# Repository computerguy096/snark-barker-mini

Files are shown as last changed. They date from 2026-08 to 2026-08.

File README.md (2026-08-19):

# The Snark Barker Mini - a miniaturized SB 1.0 Clone

The Snark Barker Mini is a function compatible clone of the original [Snark Barker](https://github.com/schlae/snark-barker), made by schlae. It implements all the features of the original Sound Blaster:

- OPL2 FM synth
- digital sound playback and recording
- gameport with MIDI IN/OUT
- SAA1099 (Creative Music System) synth 

The only major difference is the lack of a volume potentiometer. Due to the card's size and parts availability contraints, the volume is pre-set at max output, but this should not be a problem for speaker systems which have adjustable volume.

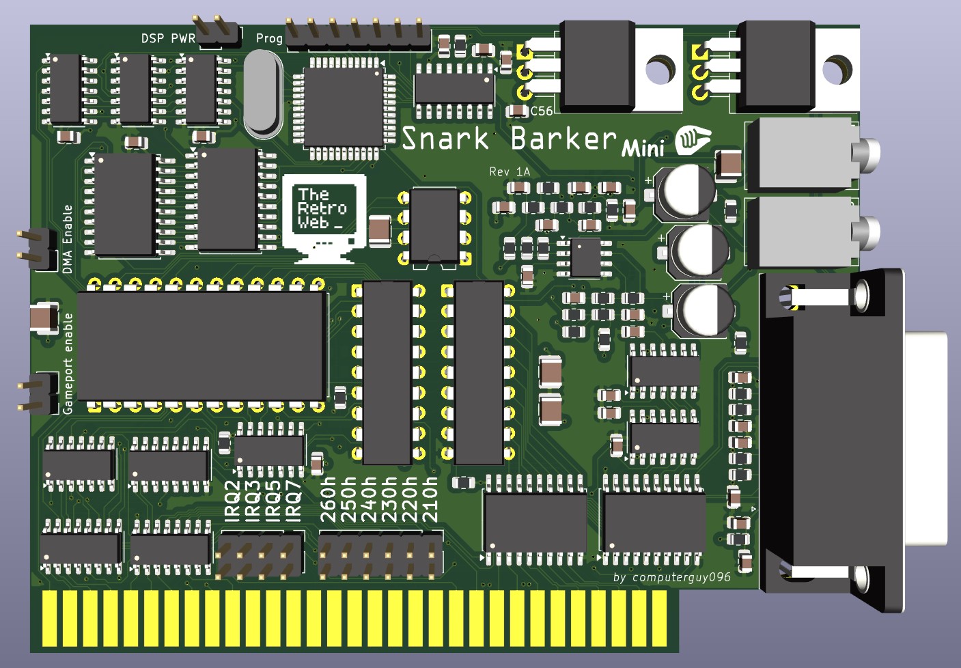
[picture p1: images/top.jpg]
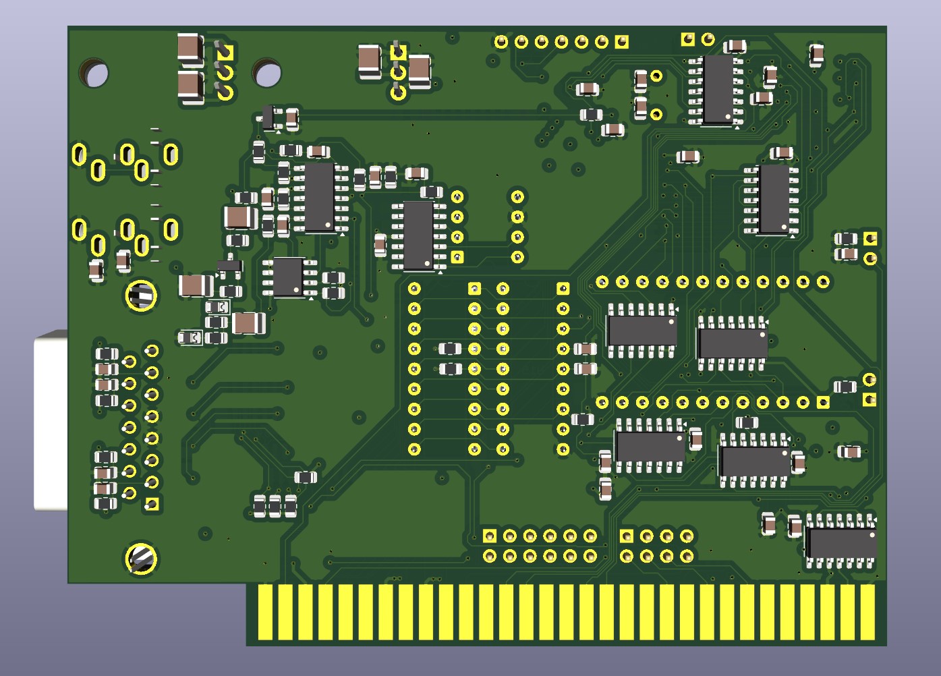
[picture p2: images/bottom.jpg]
 

## Bill Of Materials
An interactive HTML BOM is provided in `/kicad/bom` for easy parts installation. Most passives do not have silkscreen labels so this will be needed. Additionally, a CSV BOM is provided as well.

## The Firmware
This card uses an Atmel 89LP51 as a modern day replacement for the original 80C51 microcontroller Creative used to implement the DSP chip. There is a programming header provided for the DSP chip, which can be flashed with [this HEX file](firmware/sb.hex) using the tool of your choice. 

The DSP PWR jumper needs to be installed for normal operation, and removed when programming the DSP (it connects the DSP to VCC).

## Testing and Diagnostics
The card can be tested using schlae's [SBDIAG](utility/SBDIAG.EXE)

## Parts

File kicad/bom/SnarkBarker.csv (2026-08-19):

Reference | Qty | Value | DNP | Exclude from BOM | Exclude from Board | Footprint | Datasheet
C1,C2 | 2 | 30p |  |  |  | Capacitor_SMD:C_0805_2012Metric | ~
C3,C4,C37,C46,C48 | 5 | 330p |  |  |  | Capacitor_SMD:C_0805_2012Metric | ~
C5,C7 | 2 | 270p |  |  |  | Capacitor_SMD:C_0805_2012Metric | ~
C6 | 1 | 470p |  |  |  | Capacitor_SMD:C_0805_2012Metric | ~
C8 | 1 | 680p |  |  |  | Capacitor_SMD:C_0805_2012Metric | ~
C9,C10,C11,C12 | 4 | 10n |  |  |  | Capacitor_SMD:C_0805_2012Metric | ~
C13,C14,C15,C19,C20,C21,C22,C41,C45,C49,C50,C51,C52,C53,C56,C59,C60,C61,C62,C63,C64,C65,C66,C67,C68,C69,C70,C71,C72 | 29 | 100n |  |  |  | Capacitor_SMD:C_0805_2012Metric | ~
C16,C17,C18 | 3 | 22n |  |  |  | Capacitor_SMD:C_0805_2012Metric | ~
C23 | 1 | 4.7n |  |  |  | Capacitor_SMD:C_0805_2012Metric | ~
C24,C36,C39,C42,C54,C55,C57,C58,C73,C74,C75 | 11 | 10uF |  |  |  | Capacitor_SMD:C_1210_3225Metric | ~
C25,C26,C38 | 3 | 1n |  |  |  | Capacitor_SMD:C_0805_2012Metric | ~
C27,C28,C47 | 3 | 2.2n |  |  |  | Capacitor_SMD:C_0805_2012Metric | ~
C29,C30,C31 | 3 | 1uF |  |  |  | Capacitor_SMD:C_0805_2012Metric | ~
C32,C33,C43 | 3 | 100uF |  |  |  | Capacitor_SMD:CP_Elec_6.3x5.2 | ~
C34,C35 | 2 | 100p |  |  |  | Capacitor_SMD:C_0805_2012Metric | ~
C40,C44 | 2 | 47p |  |  |  | Capacitor_SMD:C_0805_2012Metric | ~
CN1 | 1 | GAME |  |  |  | Connector_Dsub:DSUB-15_Pins_Horizontal_P2.77x2.84mm_EdgePinOffset7.70mm_Housed_MountingHolesOffset9.12mm | ~
CN2 | 1 | SPKOUT |  |  |  | SB:TRS jack | ~
CN3 | 1 | MIC |  |  |  | SB:TRS jack | ~
D1,D2 | 2 | 1N4148 |  |  |  | Diode_SMD:D_0805_2012Metric | https://assets.nexperia.com/documents/data-sheet/1N4148_1N4448.pdf
J1 | 1 | Prog |  |  |  | Connector_PinHeader_2.54mm:PinHeader_1x07_P2.54mm_Vertical | ~
JP1 | 1 | I/O ADDX |  |  |  | Connector_PinHeader_2.54mm:PinHeader_2x06_P2.54mm_Vertical | ~
JP2 | 1 | IRQ |  |  |  | Connector_PinHeader_2.54mm:PinHeader_2x04_P2.54mm_Vertical | ~
JP3 | 1 | Gameport enable |  |  |  | Connector_PinHeader_2.54mm:PinHeader_1x02_P2.54mm_Vertical | ~
JP4 | 1 | DMA Enable |  |  |  | Connector_PinHeader_2.54mm:PinHeader_1x02_P2.54mm_Vertical | ~
JP5 | 1 | DSP PWR |  |  |  | Connector_PinHeader_2.54mm:PinHeader_1x02_P2.54mm_Vertical | ~
Q1,Q2 | 2 | 2N3904 |  |  |  | Package_TO_SOT_SMD:SOT-23 | https://www.onsemi.com/pub/Collateral/2N3903-D.PDF
R1,R2,R4,R20,R48,R55 | 6 | 4.7K |  |  |  | Resistor_SMD:R_0805_2012Metric | ~
R3,R5,R6,R7,R8,R9,R10,R11,R12,R36,R37 | 11 | 1K |  |  |  | Resistor_SMD:R_0805_2012Metric | ~
R13,R14,R15,R16 | 4 | 2k |  |  |  | Resistor_SMD:R_0805_2012Metric | ~
R17 | 1 | 47 |  |  |  | Resistor_SMD:R_0805_2012Metric | ~
R18,R19,R24,R25,R41 | 5 | 10K |  |  |  | Resistor_SMD:R_0805_2012Metric | ~
R21 | 1 | 2.2K |  |  |  | Resistor_SMD:R_0805_2012Metric | ~
R22,R23,R50 | 3 | 1.5K |  |  |  | Resistor_SMD:R_0805_2012Metric | ~
R26,R27 | 2 | 47K |  |  |  | Resistor_SMD:R_0805_2012Metric | ~
R28,R29,R54 | 3 | 27K |  |  |  | Resistor_SMD:R_0805_2012Metric | ~
R30,R31 | 2 | 15K |  |  |  | Resistor_SMD:R_0805_2012Metric | ~
R32,R33,R34,R35 | 4 | 20K |  |  |  | Resistor_SMD:R_0805_2012Metric | ~
R38,R39,R52 | 3 | 68K |  |  |  | Resistor_SMD:R_0805_2012Metric | ~
R40,R47,R53 | 3 | 470K |  |  |  | Resistor_SMD:R_0805_2012Metric | ~
R42,R44 | 2 | 470 |  |  |  | Resistor_SMD:R_0805_2012Metric | ~
R43 | 1 | 33K |  |  |  | Resistor_SMD:R_0805_2012Metric | ~
R45,R51 | 2 | 39K |  |  |  | Resistor_SMD:R_0805_2012Metric | ~
R46 | 1 | 100K |  |  |  | Resistor_SMD:R_0805_2012Metric | ~
R49 | 1 | 2.7K |  |  |  | Resistor_SMD:R_0805_2012Metric | ~
SL1 | 1 | 8-bit ISA slot |  |  |  | SB:ISA card edge | https://en.wikipedia.org/wiki/Industry_Standard_Architecture
U1 | 1 | L7805 |  |  |  | Package_TO_SOT_THT:TO-220-3_Horizontal_TabDown | http://www.st.com/content/ccc/resource/technical/document/datasheet/41/4f/b3/b0/12/d4/47/88/CD00000444.pdf/files/CD00000444.pdf/jcr:content/translations/en.CD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
U2 | 1 | L7905 |  |  |  | Package_TO_SOT_THT:TO-220-3_Horizontal_TabDown | http://www.st.com/content/ccc/resource/technical/document/datasheet/c9/16/86/41/c7/2b/45/f2/CD00000450.pdf/files/CD00000450.pdf/jcr:content/translations/en.CD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
U3 | 1 | DAC0808 |  |  |  | Package_SO:SOIC-16_3.9x9.9mm_P1.27mm | http://www.ti.com/lit/ds/symlink/dac0808.pdf
U4 | 1 | AT89LP51 |  |  |  | Package_QFP:TQFP-44_10x10mm_P0.8mm | https://ww1.microchip.com/downloads/en/DeviceDoc/doc2487.pdf
U5,U14,U25 | 3 | 74LS32 |  |  |  | Package_SO:SOIC-14_3.9x8.7mm_P1.27mm | http://www.ti.com/lit/gpn/sn74LS32
U6,U23,U27,U28 | 4 | 74LS74 |  |  |  | Package_SO:SOIC-14_3.9x8.7mm_P1.27mm | 74xx/74hc_hct74.pdf
U6,U28 | 2 | 74LS74 |  |  |  |  | 74xx/74hc_hct74.pdf
U7 | 1 | 74LS125 |  |  |  | Package_SO:SOIC-14_3.9x8.7mm_P1.27mm | http://www.ti.com/lit/gpn/sn74LS125
U8,U9 | 2 | 74LS374 |  |  |  | Package_SO:SOIC-20W_7.5x12.8mm_P1.27mm | http://www.ti.com/lit/gpn/sn74LS374
U10 | 1 | YM3014 |  |  |  | Package_DIP:DIP-8_W7.62mm
U11,U12 | 2 | SAA1099 |  |  |  | Package_DIP:DIP-18_W7.62mm
U13 | 1 | YM3812 |  |  |  | Package_DIP:DIP-24_W15.24mm
U15 | 1 | 74LS139 |  |  |  | Package_SO:SOIC-16_3.9x9.9mm_P1.27mm | http://www.ti.com/lit/ds/symlink/sn74ls139a.pdf
U16,U24,U26 | 3 | 74LS08 |  |  |  | Package_SO:SOIC-14_3.9x8.7mm_P1.27mm | http://www.ti.com/lit/gpn/sn74LS08
U17,U18 | 2 | 74LS138 |  |  |  | Package_SO:SOIC-16_3.9x9.9mm_P1.27mm | http://www.ti.com/lit/gpn/sn74LS138
U19,U20 | 2 | 74LS245 |  |  |  | Package_SO:SOIC-20W_7.5x12.8mm_P1.27mm | http://www.ti.com/lit/gpn/sn74LS245
U21,U22 | 2 | NE556 |  |  |  | Package_SO:SOIC-14_3.9x8.7mm_P1.27mm | http://www.ti.com/lit/ds/symlink/ne556.pdf
U29 | 1 | 74LS14 |  |  |  | Package_SO:SOIC-14_3.9x8.7mm_P1.27mm | http://www.ti.com/lit/gpn/sn74LS14
U30,U31 | 2 | LM324 |  |  |  | Package_SO:SOIC-14_3.9x8.7mm_P1.27mm | http://www.ti.com/lit/ds/symlink/lm2902-n.pdf
U32 | 1 | LM393 |  |  |  | Package_SO:SOIC-8_3.9x4.9mm_P1.27mm | http://www.ti.com/lit/ds/symlink/lm393.pdf
U33 | 1 | LM4880MX |  |  |  | Package_SO:SO-8_3.9x4.9mm_P1.27mm
Y1 | 1 | 12MHz |  |  |  | Crystal:Crystal_HC49-U_Vertical | ~

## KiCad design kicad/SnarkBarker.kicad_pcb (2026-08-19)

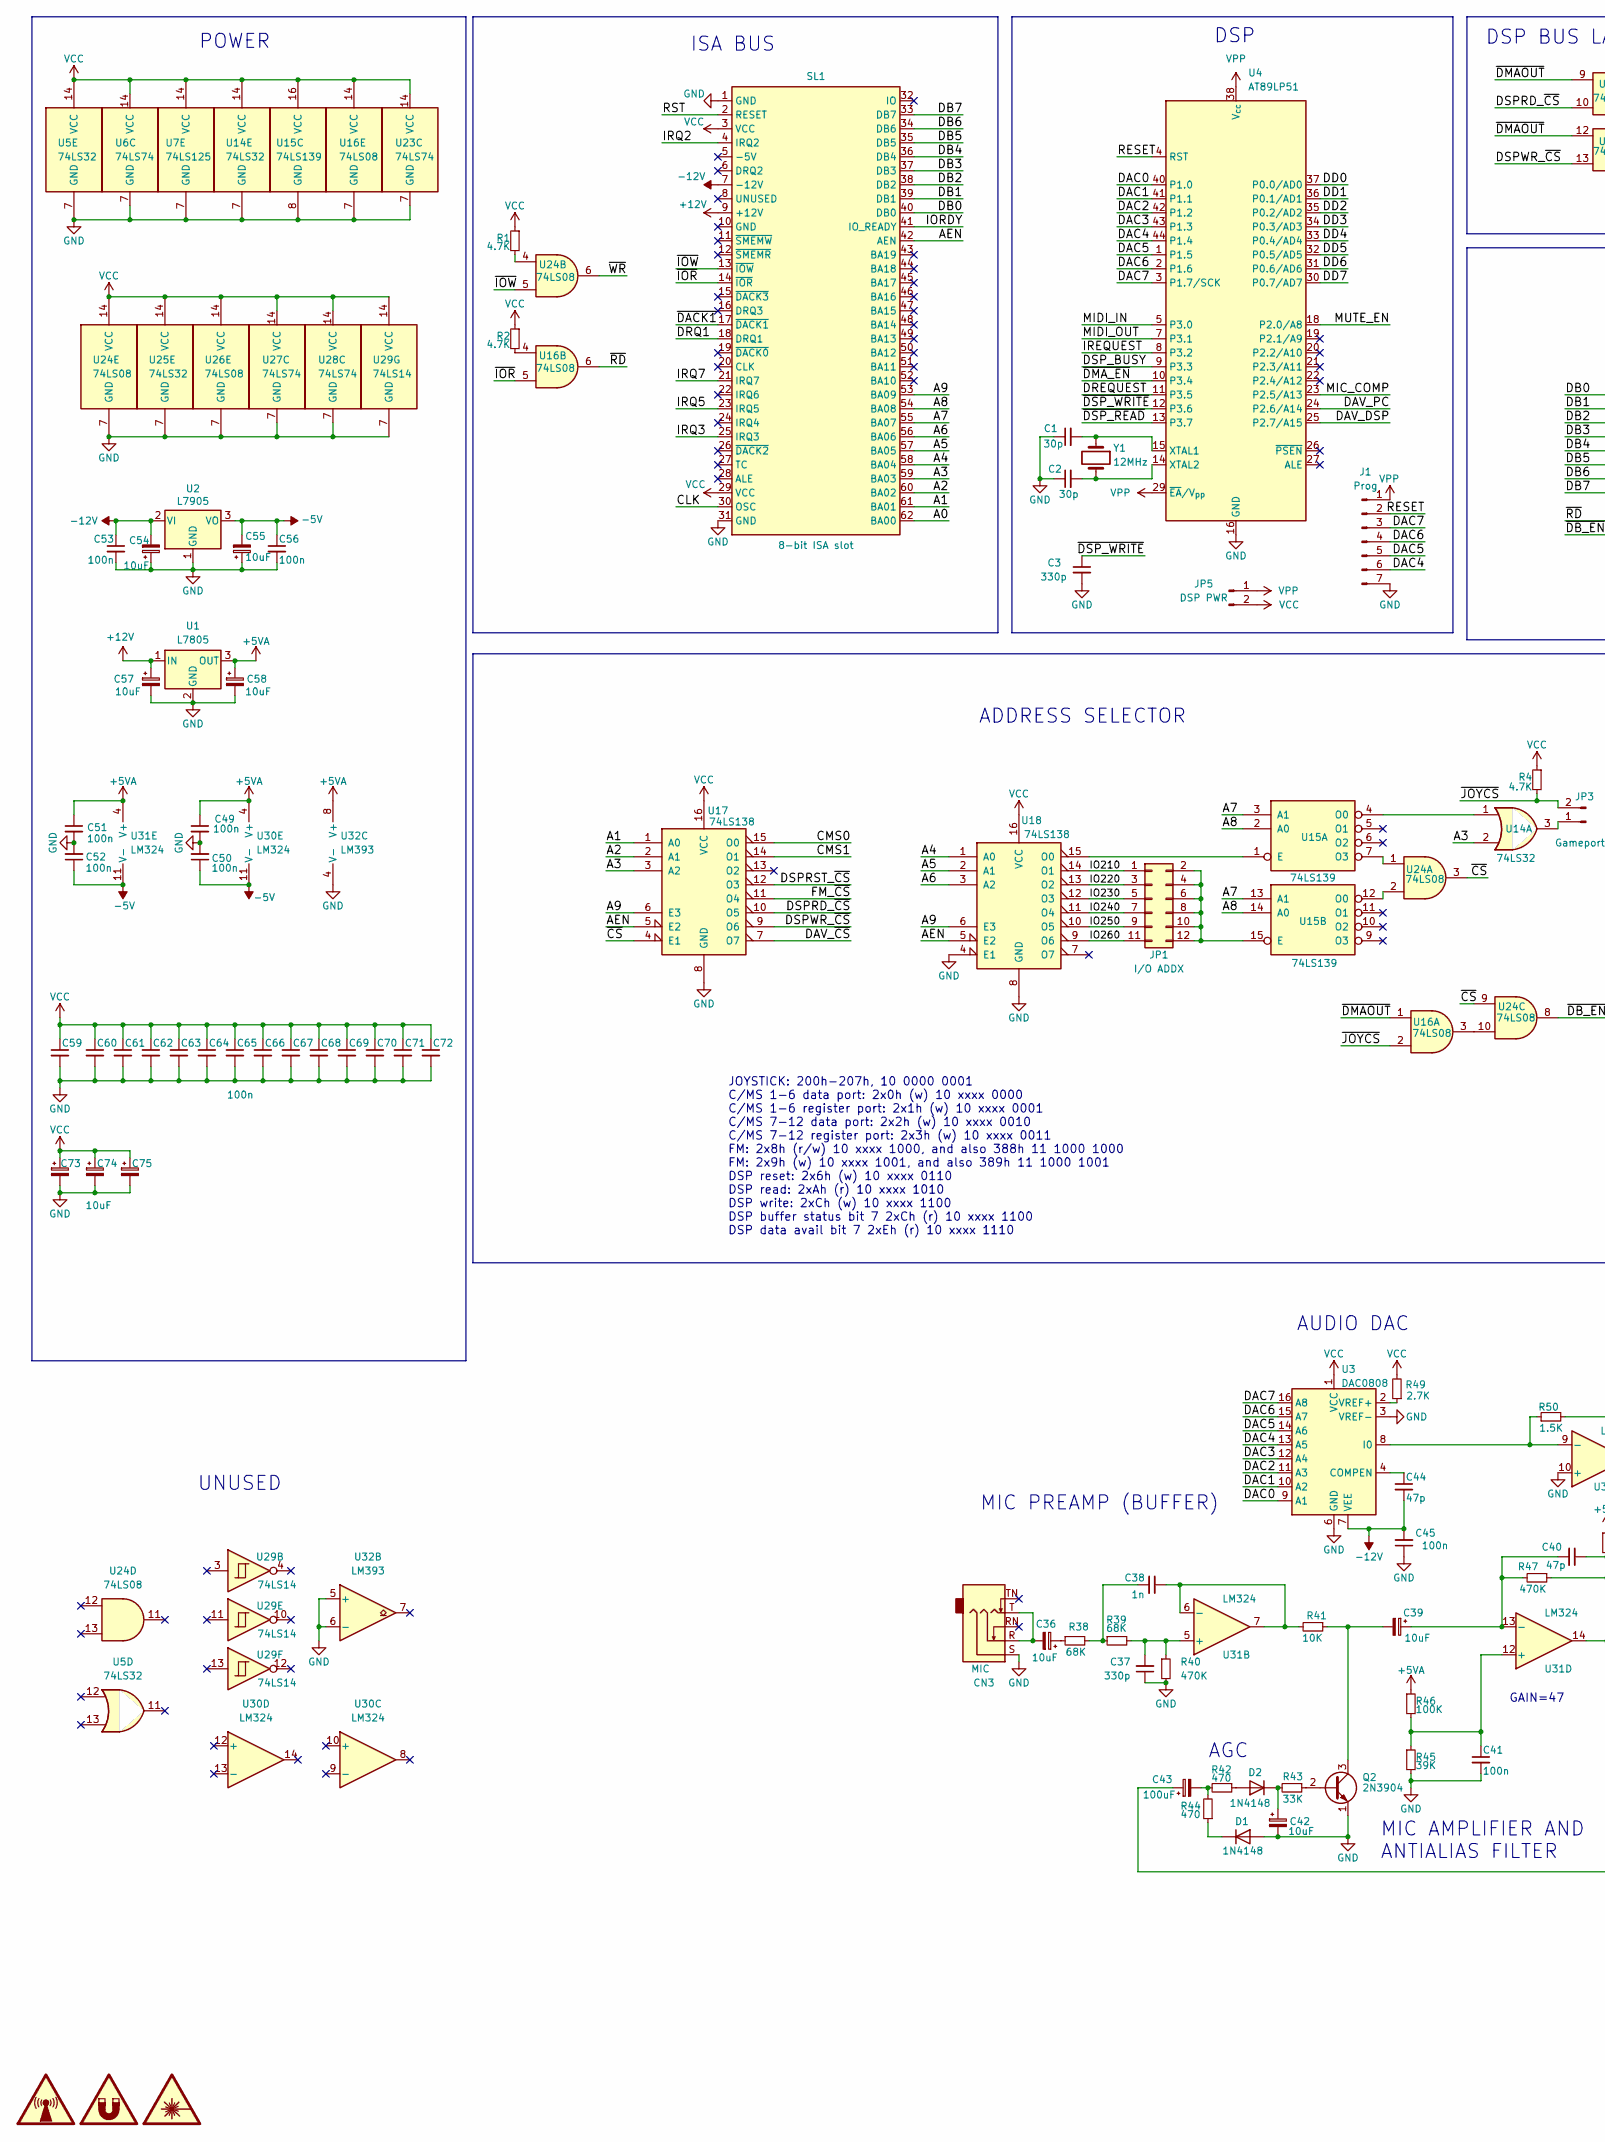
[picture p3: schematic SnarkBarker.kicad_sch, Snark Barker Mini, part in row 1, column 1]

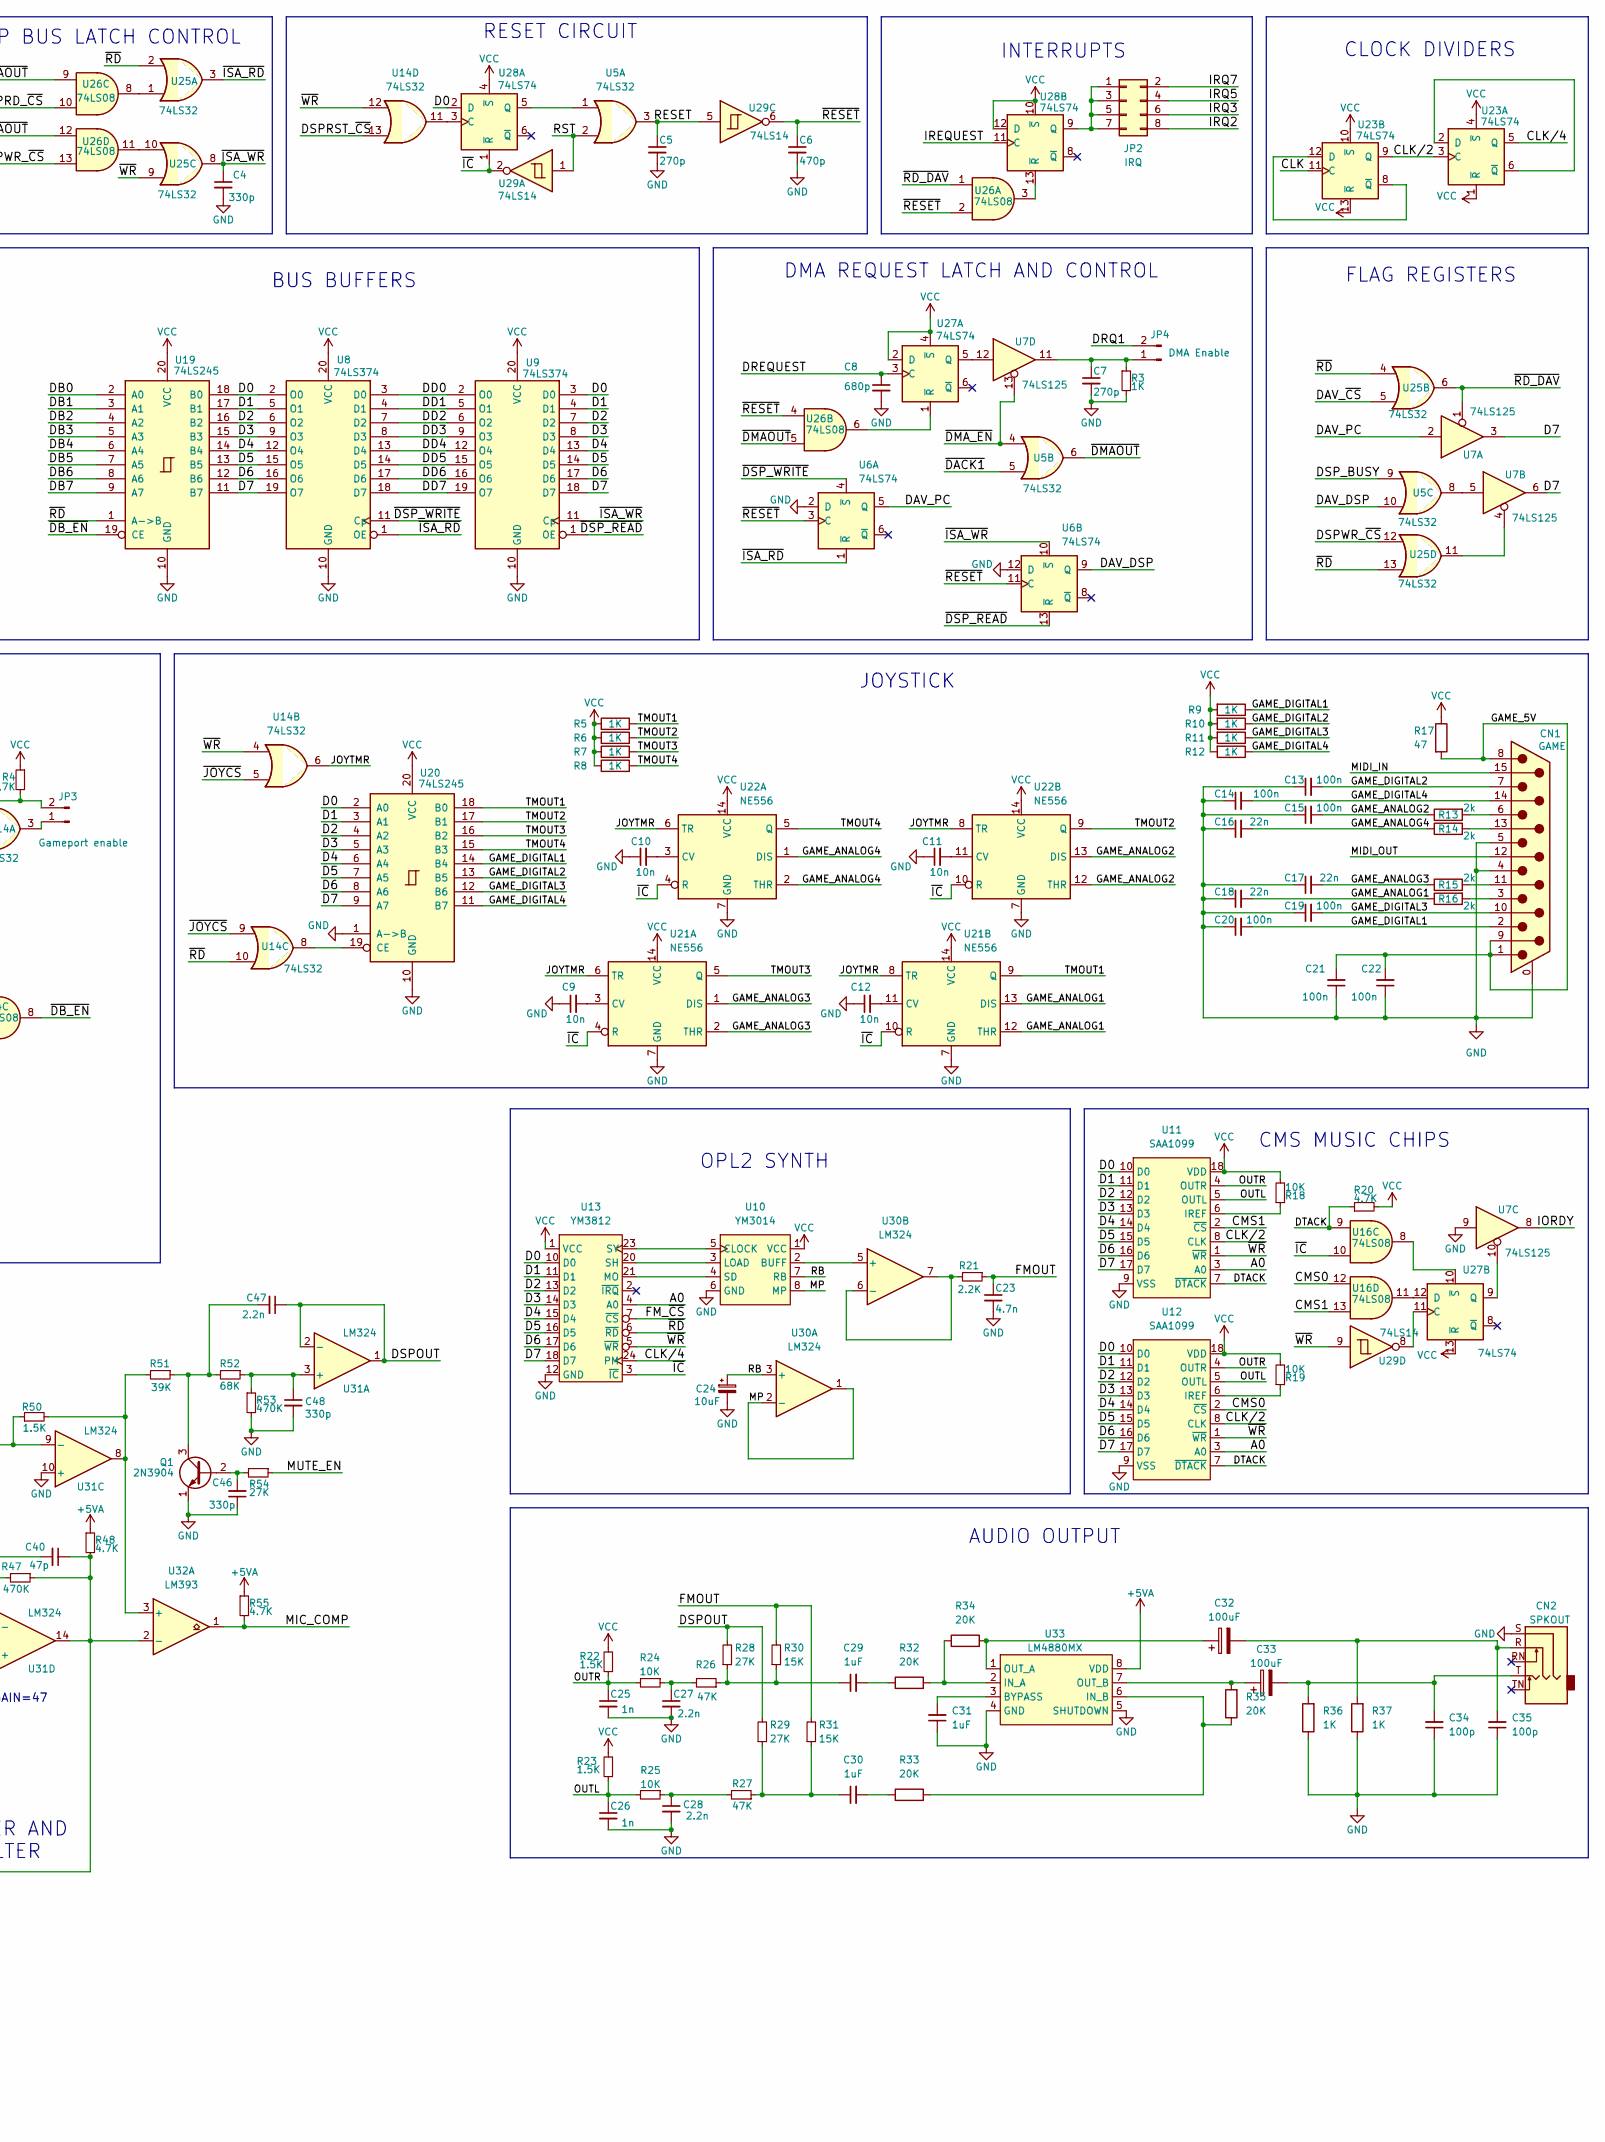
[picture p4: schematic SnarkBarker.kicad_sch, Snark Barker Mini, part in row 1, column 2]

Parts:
C1, C2: 30p; C_0805_2012Metric; Mouser 810-FG28C0G1H270JNT6
C3, C4, C37, C46, C48: 330p; C_0805_2012Metric; Mouser 810-FG28C0G1H331JNT6
C5, C7: 270p; C_0805_2012Metric; Mouser 810-FG28C0G1H271JNT0
C6: 470p; C_0805_2012Metric; Mouser 810-FG28C0G1H471JNT6
C8: 680p; C_0805_2012Metric; Mouser 810-FG28C0G1H681JNT6
C9, C10, C11, C12: 10n; C_0805_2012Metric; Mouser 810-FG28X7R1H103KNT0
C13, C14, C15, C19, C20, C21, C22: 100n; C_0805_2012Metric
C16, C17, C18: 22n; C_0805_2012Metric
C23: 4.7n; C_0805_2012Metric; Mouser 810-FG28C0G1H472JNT6
C24, C36, C39, C42, C54, C55, C57, C58, C73, C74, C75: 10uF; C_1210_3225Metric; Mouser 667-ECA-1CM100I
C25, C26, C38: 1n; C_0805_2012Metric; Mouser 810-FG28X7R1H102KNT6
C27, C28, C47: 2.2n; C_0805_2012Metric; Mouser 810-FG28X7R1H222KNT6
C29, C30, C31: 1uF; C_0805_2012Metric
C32, C33: 100uF; CP_Elec_6.3x5.2
C34, C35: 100p; C_0805_2012Metric
C40, C44: 47p; C_0805_2012Metric; Mouser 810-FG28C0G1H470JNT6
C41, C45, C49, C50, C51, C52, C53, C56, C59, C60, C61, C62, C63, C64, C65, C66, C67, C68, C69, C70, C71, C72: 100n; C_0805_2012Metric; Mouser 581-SA105E104M
C43: 100uF; CP_Elec_6.3x5.2; Mouser 667-ECA-1CM101I
CN1: GAME; DSUB-15_Pins_Horizontal_P2.77x2.84mm_EdgePinOffset7.70mm_Ho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
CN2: SPKOUT; TRS jack
CN3: MIC; TRS jack
D1, D2: 1N4148; D_0805_2012Metric; Mouser 512-1N4148
J1: Prog; PinHeader_1x07_P2.54mm_Vertical
JP1: I/O ADDX; PinHeader_2x06_P2.54mm_Vertical
JP2: IRQ; PinHeader_2x04_P2.54mm_Vertical
JP3: Gameport enable; PinHeader_1x02_P2.54mm_Vertical
JP4: DMA Enable; PinHeader_1x02_P2.54mm_Vertical
JP5: DSP PWR; PinHeader_1x02_P2.54mm_Vertical
Q1, Q2: 2N3904; SOT-23; Mouser 833-2N3904-AP
R1, R2, R4, R20, R48, R55: 4.7K; R_0805_2012Metric; Mouser 603-CFR-25JB-52-4K7
R3: 1K; R_0805_2012Metric; Mouser 603-CFR-25JR-521K
R5, R6, R7, R8, R9, R10, R11, R12, R36, R37: 1K; R_0805_2012Metric
R13, R14, R15, R16: 2k; R_0805_2012Metric
R17: 47; R_0805_2012Metric
R18, R19, R24, R25, R41: 10K; R_0805_2012Metric; Mouser 603-CFR-25JB-52-10K
R21: 2.2K; R_0805_2012Metric; Mouser 603-CFR-25JB-52-2K2
R22, R23: 1.5K; R_0805_2012Metric; Mouser 603-CFR-25JB-52-1K5
R26, R27: 47K; R_0805_2012Metric; Mouser 603-CFR-25JB-52-47K
R28, R29, R54: 27K; R_0805_2012Metric; Mouser 603-CFR-25JB-52-27K
R30, R31: 15K; R_0805_2012Metric; Mouser 603-CFR-25JB-52-15K
R32, R33, R34, R35: 20K; R_0805_2012Metric
R38, R39, R52: 68K; R_0805_2012Metric; Mouser 603-CFR-25JB-52-68K
R40, R47, R53: 470K; R_0805_2012Metric; Mouser 603-CFR-25JR-52470K
R42, R44: 470; R_0805_2012Metric; Mouser 603-CFR-25JB-52-470R
R43: 33K; R_0805_2012Metric; Mouser 603-CFR-25JB-52-33K
R45: 39K; R_0805_2012Metric; Mouser 603-MFR-25FBF52-39K
R46: 100K; R_0805_2012Metric; Mouser 603-MFR-25FBF52-100K
R49: 2.7K; R_0805_2012Metric; Mouser 603-MFR-25FBF52-2K7
R50: 1.5K; R_0805_2012Metric; Mouser 603-MFR-25FBF52-1K5
R51: 39K; R_0805_2012Metric; Mouser 603-CFR-25JB-52-39K
SL1: 8-bit ISA slot; ISA card edge
U1: L7805; TO-220-3_Horizontal_TabDown
U2: L7905; TO-220-3_Horizontal_TabDown
U3: DAC0808; SOIC-16_3.9x9.9mm_P1.27mm
U4: AT89LP51; TQFP-44_10x10mm_P0.8mm
U5, U14: 74LS32; SOIC-14_3.9x8.7mm_P1.27mm
U6: 74LS74; SOIC-14_3.9x8.7mm_P1.27mm
U7: 74LS125; SOIC-14_3.9x8.7mm_P1.27mm; Mouser 595-SN74LS125AN
U8, U9: 74LS374; SOIC-20W_7.5x12.8mm_P1.27mm; Mouser 595-SN74LS374N
U10: YM3014; DIP-8_W7.62mm
U11, U12: SAA1099; DIP-18_W7.62mm
U13: YM3812; DIP-24_W15.24mm
U15: 74LS139; SOIC-16_3.9x9.9mm_P1.27mm; Mouser 595-SN74LS139AN
U16, U24, U26: 74LS08; SOIC-14_3.9x8.7mm_P1.27mm
U17, U18: 74LS138; SOIC-16_3.9x9.9mm_P1.27mm; Mouser 595-SN74LS138NE4
U19, U20: 74LS245; SOIC-20W_7.5x12.8mm_P1.27mm; Mouser 595-SN74LS245N
U21, U22: NE556; SOIC-14_3.9x8.7mm_P1.27mm
U23, U27, U28: 74LS74; SOIC-14_3.9x8.7mm_P1.27mm; Mouser 595-SN74LS74AN
U25: 74LS32; SOIC-14_3.9x8.7mm_P1.27mm; Mouser 595-SN74LS32N
U29: 74LS14; SOIC-14_3.9x8.7mm_P1.27mm; Mouser 595-SN74LS14N
U30: LM324; SOIC-14_3.9x8.7mm_P1.27mm
U31: LM324; SOIC-14_3.9x8.7mm_P1.27mm; Mouser 512-LM324AN
U32: LM393; SOIC-8_3.9x4.9mm_P1.27mm
U33: LM4880MX; SO-8_3.9x4.9mm_P1.27mm
Y1: 12MHz; Crystal_HC49-U_Vertical

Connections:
+5VA: C49.1, C51.1, C58.1, R46.1, R48.1, R55.1, U1.3 (OUT), U30.4 (V+), U31.4 (V+), U32.8 (V+), U33.8 (VDD)
+12V: C57.1, SL1.9 (+12V), U1.1 (IN)
-5V: C50.1, C52.1, C55.2, C56.1, U2.3 (VO), U30.11 (V-), U31.11 (V-)
-12V: C44.2, C45.2, C53.1, C54.2, SL1.7 (-12V), U2.2 (VI), U3.7 (VEE)
/A0: SL1.62 (BA00), U11.3 (A0), U12.3 (A0), U13.4 (A0)
/A1: SL1.61 (BA01), U17.1 (A0)
/A2: SL1.60 (BA02), U17.2 (A1)
/A3: SL1.59 (BA03), U14.2, U17.3 (A2)
/A4: SL1.58 (BA04), U18.1 (A0)
/A5: SL1.57 (BA05), U18.2 (A1)
/A6: SL1.56 (BA06), U18.3 (A2)
/A7: SL1.55 (BA07), U15.3 (A1), U15.13 (A1)
/A8: SL1.54 (BA08), U15.2 (A0), U15.14 (A0)
/A9: SL1.53 (BA09), U17.6 (E3), U18.6 (E3)
/AEN: SL1.42 (AEN), U17.5 (E2), U18.5 (E2)
/CLK: SL1.30 (OSC), U23.11 (C)
/CLK/2: U11.8 (CLK), U12.8 (CLK), U23.3 (C), U23.9 (Q)
/CLK/4: U13.24 (PM), U23.5 (Q)
/CMS0: U12.2 (~CS), U16.12, U17.15 (O0)
/CMS1: U11.2 (~CS), U16.13, U17.14 (O1)
/D0: U8.2 (O0), U9.3 (D0), U11.10 (D0), U12.10 (D0), U13.10 (D0), U19.18 (B0), U20.2 (A0), U28.2 (D)
/D1: U8.5 (O1), U9.4 (D1), U11.11 (D1), U12.11 (D1), U13.11 (D1), U19.17 (B1), U20.3 (A1)
/D2: U8.6 (O2), U9.7 (D2), U11.12 (D2), U12.12 (D2), U13.13 (D2), U19.16 (B2), U20.4 (A2)
/D3: U8.9 (O3), U9.8 (D3), U11.13 (D3), U12.13 (D3), U13.14 (D3), U19.15 (B3), U20.5 (A3)
/D4: U8.12 (O4), U9.13 (D4), U11.14 (D4), U12.14 (D4), U13.15 (D4), U19.14 (B4), U20.6 (A4)
/D5: U8.15 (O5), U9.14 (D5), U11.15 (D5), U12.15 (D5), U13.16 (D5), U19.13 (B5), U20.7 (A5)
/D6: U8.16 (O6), U9.17 (D6), U11.16 (D6), U12.16 (D6), U13.17 (D6), U19.12 (B6), U20.8 (A6)
/D7: U7.3, U7.6, U8.19 (O7), U9.18 (D7), U11.17 (D7), U12.17 (D7), U13.18 (D7), U19.11 (B7), U20.9 (A7)
/DAC0: U3.9 (A1), U4.40 (P1.0)
/DAC1: U3.10 (A2), U4.41 (P1.1)
/DAC2: U3.11 (A3), U4.42 (P1.2)
/DAC3: U3.12 (A4), U4.43 (P1.3)
/DAC4: J1.6, U3.13 (A5), U4.44 (P1.4)
/DAC5: J1.5, U3.14 (A6), U4.1 (P1.5)
/DAC6: J1.4, U3.15 (A7), U4.2 (P1.6)
/DAC7: J1.3, U3.16 (A8), U4.3 (P1.7/SCK)
/DAV_DSP: U4.25 (P2.7/A15), U5.10, U6.9 (Q)
/DAV_PC: U4.24 (P2.6/A14), U6.5 (Q), U7.2
/DAV_~CS: U17.7 (O7), U25.5
/DB0: SL1.40 (DB0), U19.2 (A0)
/DB1: SL1.39 (DB1), U19.3 (A1)
/DB2: SL1.38 (DB2), U19.4 (A2)
/DB3: SL1.37 (DB3), U19.5 (A3)
/DB4: SL1.36 (DB4), U19.6 (A4)
/DB5: SL1.35 (DB5), U19.7 (A5)
/DB6: SL1.34 (DB6), U19.8 (A6)
/DB7: SL1.33 (DB7), U19.9 (A7)
/DD0: U4.37 (P0.0/AD0), U8.3 (D0), U9.2 (O0)
/DD1: U4.36 (P0.1/AD1), U8.4 (D1), U9.5 (O1)
/DD2: U4.35 (P0.2/AD2), U8.7 (D2), U9.6 (O2)
/DD3: U4.34 (P0.3/AD3), U8.8 (D3), U9.9 (O3)
/DD4: U4.33 (P0.4/AD4), U8.13 (D4), U9.12 (O4)
/DD5: U4.32 (P0.5/AD5), U8.14 (D5), U9.15 (O5)
/DD6: U4.31 (P0.6/AD6), U8.17 (D6), U9.16 (O6)
/DD7: U4.30 (P0.7/AD7), U8.18 (D7), U9.19 (O7)
/DREQUEST: C8.1, U4.11 (P3.5), U27.3 (C)
/DRQ1: JP4.2, SL1.18 (DRQ1)
/DSPOUT: C47.1, R28.2, R29.2, U31.1, U31.2 (-)
/DSPRD_~CS: U17.10 (O5), U26.10
/DSPRST_~CS: U14.13, U17.12 (O3)
/DSPWR_~CS: U17.9 (O6), U25.12, U26.13
/DSP_BUSY: U4.9 (P3.3), U5.9
/DTACK: R20.1, U11.7 (~DTACK), U12.7 (~DTACK), U16.9
/FMOUT: C23.1, R21.1, R30.2, R31.2
/FM_~CS: U13.7 (~CS), U17.11 (O4)
/GAME_5V: C21.2, C22.2, CN1.1, CN1.8, CN1.9, R17.2
/GAME_ANALOG1: C18.2, R16.1, U21.12 (THR), U21.13 (DIS)
/GAME_ANALOG2: C15.2, R13.1, U22.12 (THR), U22.13 (DIS)
/GAME_ANALOG3: C17.2, R15.1, U21.1 (DIS), U21.2 (THR)
/GAME_ANALOG4: C16.2, R14.1, U22.1 (DIS), U22.2 (THR)
/GAME_DIGITAL1: C20.2, CN1.2, R9.1, U20.14 (B4)
/GAME_DIGITAL2: C13.2, CN1.7, R10.1, U20.13 (B5)
/GAME_DIGITAL3: C19.2, CN1.10, R11.1, U20.12 (B6)
/GAME_DIGITAL4: C14.2, CN1.14, R12.1, U20.11 (B7)
/IO210: JP1.1, U18.14 (O1)
/IO220: JP1.3, U18.13 (O2)
/IO230: JP1.5, U18.12 (O3)
/IO240: JP1.7, U18.11 (O4)
/IO250: JP1.9, U18.10 (O5)
/IO260: JP1.11, U18.9 (O6)
/IORDY: SL1.41 (IO_READY), U7.8
/IREQUEST: U4.8 (P3.2), U28.11 (C)
/IRQ2: JP2.8, SL1.4 (IRQ2)
/IRQ3: JP2.6, SL1.25 (IRQ3)
/IRQ5: JP2.4, SL1.23 (IRQ5)
/IRQ7: JP2.2, SL1.21 (IRQ7)
/JOYTMR: U14.6, U21.6 (TR), U21.8 (TR), U22.6 (TR), U22.8 (TR)
/MIC_COMP: R55.2, U4.23 (P2.5/A13), U32.1
/MIDI_IN: CN1.15, U4.5 (P3.0)
/MIDI_OUT: CN1.12, U4.7 (P3.1)
/MP: U10.8 (MP), U30.1, U30.2 (-)
/MUTE_EN: R54.1, U4.18 (P2.0/A8)
/OUTL: C26.1, R23.1, R25.2, U11.5 (OUTL), U12.5 (OUTL)
/OUTR: C25.1, R22.1, R24.2, U11.4 (OUTR), U12.4 (OUTR)
/RB: C24.1, U10.7 (RB), U30.3 (+)
/RESET: C5.1, J1.2, U4.4 (RST), U5.3, U29.5
/RST: SL1.2 (RESET), U5.2, U29.1
/TMOUT1: R5.2, U20.18 (B0), U21.9 (Q)
/TMOUT2: R6.2, U20.17 (B1), U22.9 (Q)
/TMOUT3: R7.2, U20.16 (B2), U21.5 (Q)
/TMOUT4: R8.2, U20.15 (B3), U22.5 (Q)
/~CS: U17.4 (E1), U24.3, U24.9
/~DACK1: SL1.17 (~DACK1), U5.5
/~DB_EN: U19.19 (CE), U24.8
/~DMAOUT: U5.6, U16.1, U26.5, U26.9, U26.12
/~DMA_EN: U4.10 (P3.4), U5.4, U7.13
/~DSP_READ: U4.13 (P3.7), U6.13 (~R), U9.1 (OE)
/~DSP_WRITE: C3.1, U4.12 (P3.6), U6.4 (~S), U8.11 (Cp)
/~IC: U13.3 (~IC), U16.10, U21.4 (R), U21.10 (R), U22.4 (R), U22.10 (R), U28.1 (~R), U29.2
/~IOR: SL1.14 (~IOR), U16.5
/~IOW: SL1.13 (~IOW), U24.5
/~ISA_RD: U6.1 (~R), U8.1 (OE), U25.3
/~ISA_WR: C4.1, U6.10 (~S), U9.11 (Cp), U25.8
/~JOYCS: JP3.2, R4.2, U14.5, U14.9, U16.2
/~RD_DAV: U7.1, U25.6, U26.1
/~RD: U13.6 (~RD), U14.10, U16.6, U19.1 (A->B), U25.2, U25.4, U25.13
/~RESET: C6.1, U6.3 (C), U6.11 (C), U26.2, U26.4, U29.6
/~WR: U11.1 (~WR), U12.1 (~WR), U13.5 (~WR), U14.4, U14.12, U24.6, U25.9, U29.9
GND: C1.1, C2.1, C3.2, C4.2, C5.2, C6.2, C7.2, C8.2, C9.1, C10.1, C11.1, C12.1, C13.1, C14.1, C15.1, C16.1, C17.1, C18.1, C19.1, C20.1, C21.1, C22.1, C23.2, C24.2, C25.2, C26.2, C27.2, C28.2, C31.1, C34.1, C35.1, C37.1, C41.2, C42.2, C45.1, C46.1, C48.2, C49.2, C50.2, C51.2, C52.2, C53.2, C54.1, C55.1, C56.2, C57.2, C58.2, C59.2, C60.2, C61.2, C62.2, C63.2, C64.2, C65.2, C66.2, C67.2, C68.2, C69.2, C70.2, C71.2, C72.2, C73.2, C74.2, C75.2, CN1.0 (PAD), CN1.4, CN1.5, CN2.S, CN3.S, D1.2 (A), J1.7, Q1.1 (E), Q2.1 (E), R3.2, R36.1, R37.1, R40.2, R45.2, R53.2, SL1.1 (GND), SL1.31 (GND), U1.2 (GND), U2.1 (GND), U3.3 (VREF-), U3.6 (GND), U4.16 (GND), U4.17 (GND), U5.7 (GND), U6.2 (D), U6.7 (GND), U6.12 (D), U7.7 (GND), U7.9, U8.10 (GND), U9.10 (GND), U10.6 (GND), U11.9 (VSS), U12.9 (VSS), U13.12 (GND), U14.7 (GND), U15.8 (GND), U16.7 (GND), U17.8 (GND), U18.4 (E1), U18.8 (GND), U19.10 (GND), U20.1 (A->B), U20.10 (GND), U21.7 (GND), U22.7 (GND), U23.7 (GND), U24.7 (GND), U25.7 (GND), U26.7 (GND), U27.7 (GND), U28.7 (GND), U29.7 (GND), U31.10 (+), U32.4 (V-), U32.5 (+), U32.6 (-), U33.4 (GND), U33.5 (SHUTDOWN)
unnamed: C27.1, R24.1, R26.2
unnamed: C28.1, R25.1, R27.2
unnamed: C29.1, R26.1, R28.1, R30.1
unnamed: C29.2, R32.1
unnamed: C30.1, R27.1, R29.1, R31.1
unnamed: C30.2, R33.1
unnamed: C32.2, C35.2, CN2.R, R37.2
unnamed: C33.2, C34.2, CN2.T, R36.2
unnamed: C36.1, R38.1
unnamed: C36.2, CN3.R, CN3.T
unnamed: C38.2, R38.2, R39.1
unnamed: C43.2, R42.2, R44.2
unnamed: CN1.13, R14.2
unnamed: CN1.11 (P111), R15.2
unnamed: CN1.3, R16.2
unnamed: CN1.6, R13.2
unnamed: D1.1 (K), R44.1
unnamed: D2.2 (A), R42.1
unnamed: C42.1, D2.1 (K), R43.2
unnamed: JP1.2, JP1.4, JP1.6, JP1.8, JP1.10, JP1.12, U15.15 (E)
unnamed: JP2.1, JP2.3, JP2.5, JP2.7, U28.9 (Q)
unnamed: JP3.1, U14.3
unnamed: C7.1, JP4.1, R3.1, U7.11
unnamed: C46.2, Q1.2 (B), R54.2
unnamed: C47.2, Q1.3 (C), R51.1, R52.2
unnamed: Q2.2 (B), R43.1
unnamed: C39.2, Q2.3 (C), R41.1
unnamed: R1.2, U24.4
unnamed: R2.2, U16.4
unnamed: C44.1, U3.4 (COMPEN)
unnamed: R50.1, U3.8 (I0), U31.9 (-)
unnamed: R49.1, U3.2 (VREF+)
unnamed: C1.2, U4.15 (XTAL1), Y1.1
unnamed: C2.2, U4.14 (XTAL2), Y1.2
unnamed: U5.8, U7.5
unnamed: U10.2 (BUFF), U30.5 (+)
unnamed: U10.5 (CLOCK), U13.23 (SY)
unnamed: U10.3 (LOAD), U13.20 (SH)
unnamed: U10.4 (SD), U13.21 (MO)
unnamed: R18.1, U11.6 (IREF)
unnamed: R19.1, U12.6 (IREF)
unnamed: U15.1 (E), U18.15 (O0)
unnamed: U14.1, U15.4 (O0)
unnamed: U15.7 (O3), U24.1
unnamed: U15.12 (O0), U24.2
unnamed: U16.3, U24.10
unnamed: U14.8, U20.19 (CE)
unnamed: C9.2, U21.3 (CV)
unnamed: C12.2, U21.11 (CV)
unnamed: C10.2, U22.3 (CV)
unnamed: C11.2, U22.11 (CV)
unnamed: U23.2 (D), U23.6 (~Q)
unnamed: U23.8 (~Q), U23.12 (D)
unnamed: U25.1, U26.8
unnamed: U25.10, U26.11
unnamed: U7.4, U25.11
unnamed: U7.12, U27.5 (Q)
unnamed: U26.6, U27.1 (~R)
unnamed: U27.11 (C), U29.8
unnamed: U16.11, U27.12 (D)
unnamed: U7.10, U27.9 (Q)
unnamed: U16.8, U27.10 (~S)
unnamed: U14.11, U28.3 (C)
unnamed: U5.1, U28.5 (Q)
unnamed: U26.3, U28.13 (~R)
unnamed: R21.2, U30.6 (-), U30.7
unnamed: C48.1, R52.1, R53.1, U31.3 (+)
unnamed: C37.2, R39.2, R40.1, U31.5 (+)
unnamed: C38.1, R41.2, U31.6 (-), U31.7
unnamed: C41.1, R45.1, R46.2, U31.12 (+)
unnamed: C39.1, C40.2, R47.2, U31.13 (-)
unnamed: R50.2, R51.2, U31.8, U32.3 (+)
unnamed: C40.1, C43.1, R47.1, R48.2, U31.14, U32.2 (-)
unnamed: C31.2, U33.3 (BYPASS)
unnamed: R32.2, R34.1, U33.2 (IN_A)
unnamed: R33.2, R35.1, U33.6 (IN_B)
unnamed: C32.1, R34.2, U33.1 (OUT_A)
unnamed: C33.1, R35.2, U33.7 (OUT_B)
VCC: C59.1, C60.1, C61.1, C62.1, C63.1, C64.1, C65.1, C66.1, C67.1, C68.1, C69.1, C70.1, C71.1, C72.1, C73.1, C74.1, C75.1, JP5.2, R1.1, R2.1, R4.1, R5.1, R6.1, R7.1, R8.1, R9.2, R10.2, R11.2, R12.2, R17.1, R18.2, R19.2, R20.2, R22.2, R23.2, R49.2, SL1.3 (VCC), SL1.29 (VCC), U3.1 (VCC), U5.14 (VCC), U6.14 (VCC), U7.14 (VCC), U8.20 (VCC), U9.20 (VCC), U10.1 (VCC), U11.18 (VDD), U12.18 (VDD), U13.1 (VCC), U14.14 (VCC), U15.16 (VCC), U16.14 (VCC), U17.16 (VCC), U18.16 (VCC), U19.20 (VCC), U20.20 (VCC), U21.14 (VCC), U22.14 (VCC), U23.1 (~R), U23.4 (~S), U23.10 (~S), U23.13 (~R), U23.14 (VCC), U24.14 (VCC), U25.14 (VCC), U26.14 (VCC), U27.2 (D), U27.4 (~S), U27.13 (~R), U27.14 (VCC), U28.4 (~S), U28.10 (~S), U28.12 (D), U28.14 (VCC), U29.14 (VCC)
VPP: J1.1, JP5.1, U4.29 (~EA/V_{pp}), U4.38 (V_{cc})

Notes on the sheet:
DSP BUS LATCH CONTROL
POWER
GAIN=47
BUS BUFFERS
AUDIO OUTPUT
OPL2 SYNTH
RESET CIRCUIT
MIC PREAMP (BUFFER)
AGC
CMS MUSIC CHIPS
JOYSTICK
ADDRESS SELECTOR
ISA BUS
JOYSTICK: 200h-207h, 10 0000 0001 C/MS 1-6 data port: 2x0h (w) 10 xxxx 0000 C/MS 1-6 register port: 2x1h (w) 10 xxxx 0001 C/MS 7-12 data port: 2x2h (w) 10 xxxx 0010 C/MS 7-12 register port: 2x3h (w) 10 xxxx 0011 FM: 2x8h (r/w) 10 xxxx 1000, and also 388h 11 1000 1000 FM: 2x9h (w) 10 xxxx 1001, and 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
INTERRUPTS
DMA REQUEST LATCH AND CONTROL
DSP
AUDIO DAC
MIC AMPLIFIER AND ANTIALIAS FILTER
UNUSED
FLAG REGISTERS
CLOCK DIVIDERS

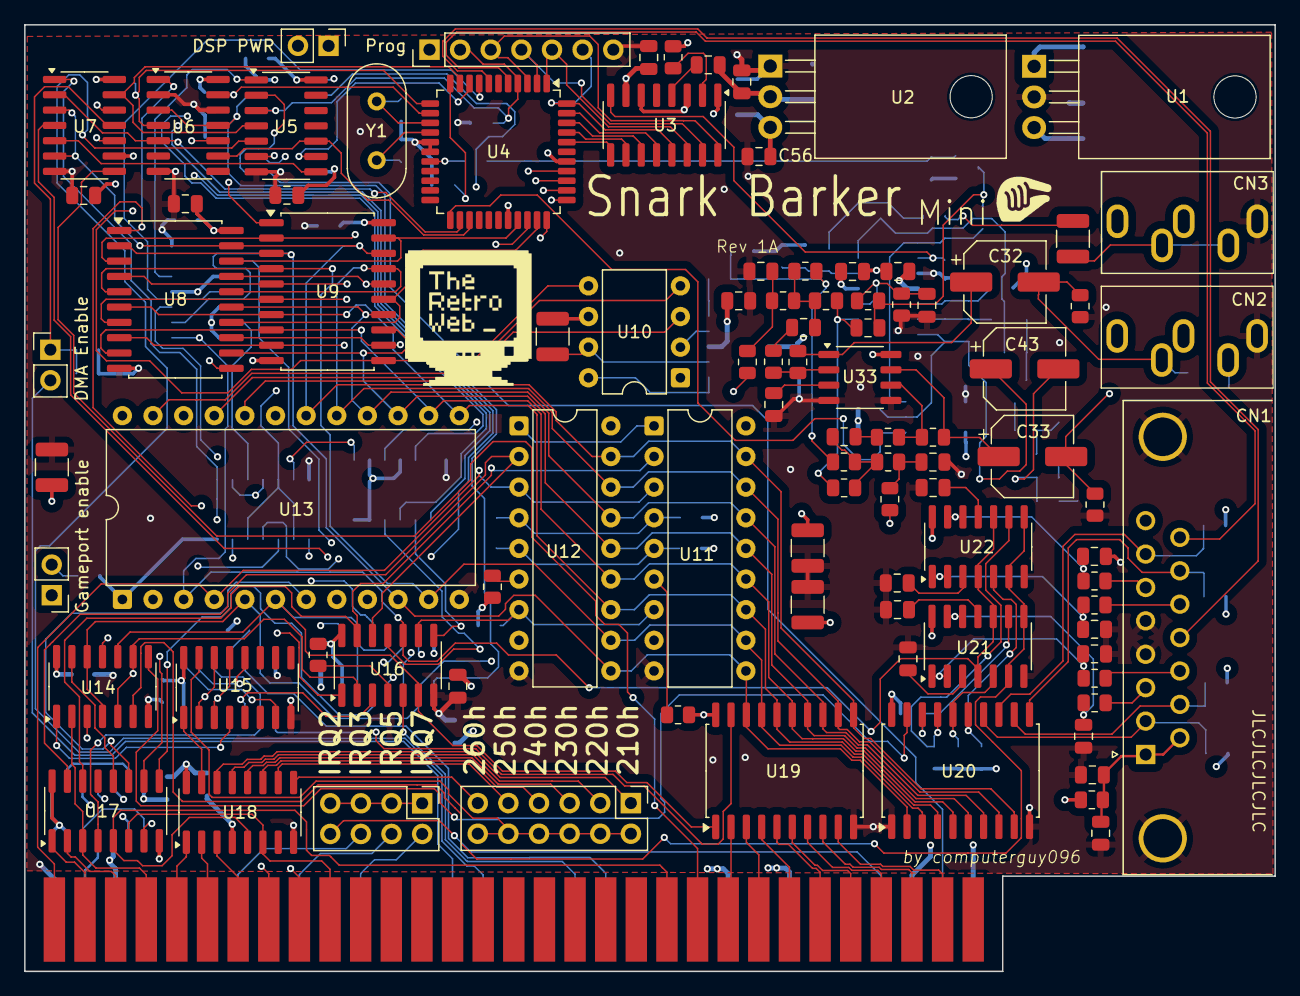
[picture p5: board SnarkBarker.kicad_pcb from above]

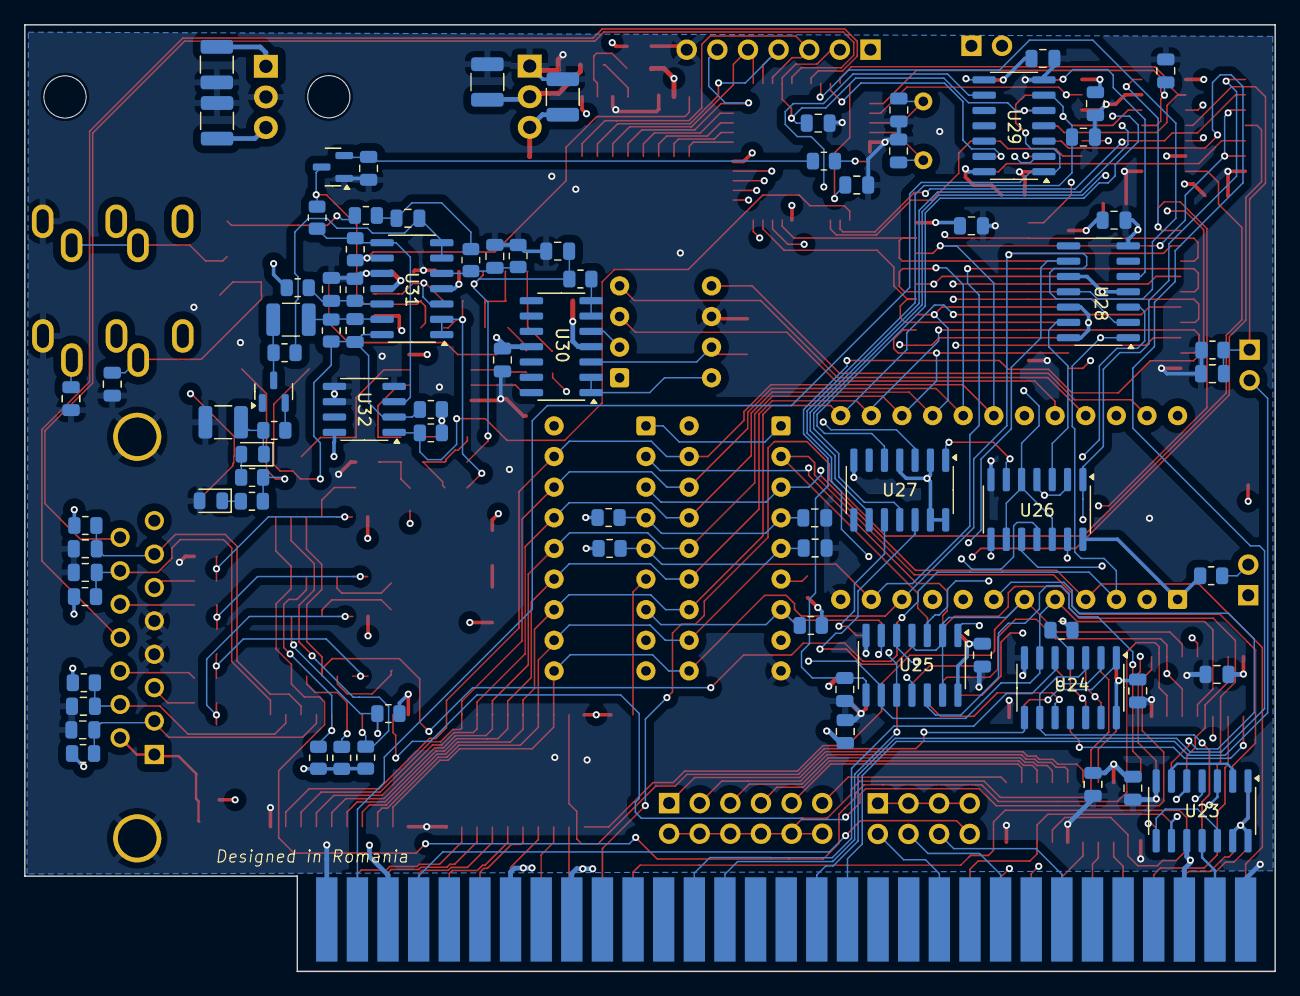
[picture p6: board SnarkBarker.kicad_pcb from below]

Board: 4 copper layers, 103.7 x 78.5 mm, 179 parts (83 on the bottom side), 199 nets.

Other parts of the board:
G1: LOGO; trw_logo

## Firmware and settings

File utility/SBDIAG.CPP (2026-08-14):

//
// Snark Barker Diagnostic Program
// Copyright (c) 2020 Eric Schlaepfer
// This work is licensed under the Creative Commons Attribution-ShareAlike 4.0
// International License. To view a copy of this license, visit
// http://creativecommons.org/licenses/by-sa/4.0/ or send a letter to Creative
// Commons, PO Box 1866, Mountain View, CA 94042, USA.
//

// Need to implement:
//   CMS chips

// Compile using Borland Turbo C++ 3.1 using the Large memory model


#include <alloc.h>
#include <conio.h>
#include <dos.h>
#include <math.h>
#include <stdio.h>
#include <stdlib.h>
#include <string.h>
#include <time.h>

#ifdef __cplusplus
#define __CPPARGS ...
#else
#define __CPPARGS
#endif

// Use Numerically-Controlled Oscillator to generate digital sine wave
#define USE_NCO 1

// Macros return upper or lower byte of a word.
#define HIGH(val) ((val) >> 8)
#define LOW(val) ((val) & 0xFF)

// Macros calculate the linear address and page of a far pointer.
#define LINEAR_ADDRESS(val) (((unsigned long)FP_SEG(val) << 4) + (unsigned long)FP_OFF(val))
#define PAGE(val) (LINEAR_ADDRESS(val) >> 16)

// Programmable Interrupt Controller registers and command.
#define PIC1_COMMAND 0x20
#define PIC1_MASK 0x21
#define PIC_EOI 0x20

// Offset between physical interrupts and logical interrupts.
#define INTERRUPT_OFFSET 0x8

// DMA controller macros to calculate address and length for a channel.
#define DMA_ADDRESS(channel) ((channel) * 2)
#define DMA_LENGTH(channel) ((channel) * 2 + 1)

// DMA controller registers and register bits.
#define DMA_MASK 0x0A
#define  DMA_MASK_SET 0x04
#define  DMA_MASK_CLEAR 0x00
#define DMA_MODE 0x0B
#define  DMA_MODE_READ 0x08
#define  DMA_MODE_WRITE 0x04
#define  DMA_MODE_SINGLE 0x40
#define  DMA_MODE_AUTO 0x10
#define DMA_CLEAR 0x0C

// Sound Blaster DSP I/O port offsets
#define DSP_RESET 0x6
#define DSP_READ 0xA
#define DSP_WRITE 0xC
#define DSP_WRITE_STATUS 0xC
#define DSP_READ_STATUS 0xE

// Sound Blaster DSP commands.
#define DSP_DMA_DAC 0x14
#define DSP_DIRECT_ADC 0x20
#define DSP_MIDI_READ_POLL 0x30
#define DSP_MIDI_WRITE_POLL 0x38
#define DSP_SET_TIME_CONSTANT 0x40
#define DSP_HALT_DMA 0xD0
#define DSP_ENABLE_SPEAKER 0xD1
#define DSP_DISABLE_SPEAKER 0xD3
#define DSP_VERSION 0xE1
#define DSP_WRITETEST 0xE4
#define DSP_READTEST 0xE8
#define DSP_SINE 0xF0
#define DSP_IRQ 0xF2
#define DSP_CHECKSUM 0xF4

// Macro to calculate Sound Blaster time constant from sample rate.
#define SAMPLE_RATE_TO_TC(a) (256 - (1000000 / (a)))

// Ad Lib stuff
#define ADLIB_INDEX_DELAY 6
#define ADLIB_WRITE_DELAY 36

// Ad Lib registers
#define ADLIB_STATUS    0x00
#define ADLIB_TEST      0x01
#define ADLIB_TIMER1    0x02
#define ADLIB_TIMER2    0x03
#define ADLIB_CONTROL   0x04
#define ADLIB_CSW       0x08
#define ADLIB_TVSKSR    0x20
#define ADLIB_KSLVOL    0x40
#define ADLIB_AD        0x60
#define ADLIB_SR        0x80
#define ADLIB_FREQ      0xA0
#define ADLIB_KEYBLOCK  0xB0
#define ADLIB_PERC      0xBD
#define ADLIB_OUT       0xC0
#define ADLIB_WAVE      0xE0

// CMS chip offsets
#define CMS_DATA1       0x00
#define CMS_REG1        0x01
#define CMS_DATA2       0x02
#define CMS_REG2        0x03

// CMS registers
#define CMS_AMPL0       0x00
#define CMS_FREQ0       0x08
#define CMS_OCT01       0x10
#define CMS_FE          0x14
#define CMS_NE          0x15
#define CMS_NG          0x16
#define CMS_EG0         0x18
#define CMS_ENABLE      0x1C


// RIFF WAVE file header.
typedef struct {
        char signature[4];     // 'RIFF'
        unsigned long length;  // Entire length of wave - 8 bytes.
        char format[4];        // 'WAVE'
        char fmt_id[4];        // 'fmt '
        unsigned long fmt_length; // Length of format struct.
        unsigned int audio_format;
        unsigned int channels;
        unsigned long sample_rate;
        unsigned long byte_rate;
        unsigned int block_align;
        unsigned int bits_per_sample;
} RIFF_FMT_CHUNK;

// RIFF wave file data header.
typedef struct {
        char signature[4]; // 'data'
        unsigned long length; // Length of waveform data.
} DATA_CHUNK;

// Menu item structure for menuing system
typedef struct {
        char name[32];
        void (*menufunc)();
        void *submenu;
} MENU_ITEM;

// Text mode info
struct text_info curtextmode;

// Sound Blaster port, interrupt, and DMA settings.
int sb_port = 0x220;
int sb_interrupt = 0x5;
int sb_dma = 0x1;

// Ad Lib and joystick port settings
int ad_port = 0x388;
int joy_port = 0x201;

// Saved interrupt handler and mask setting.
int old_pic_mask;
void interrupt (*old_interrupt_handler)(__CPPARGS);

// Flag set by interrupt service routine when interrupt gets handled.
volatile int interrupt_detected;

// DMA page register I/O ports in DMA channel order (0, 1, 2, 3).
const int dma_page_register[] = {0x87, 0x83, 0x81, 0x82};

// Sine wave table
unsigned char sine_table[256];


// Wait for data to become available from Sound Blaster DSP.
int wait_read(void)
{
        unsigned int i;
        for (i = 0; i < 1000; i++) {
                if (inportb(sb_port + DSP_READ_STATUS) & 0x80) {
                        return 1;
                }
                delay(1);
        }
        return 0; // Timed out.
}


// Wait for Sound Blaster DSP to be ready to receive a new byte.
int wait_write(void)
{
        unsigned int i;
        for (i = 0; i < 1000; i++) {
                if (!(inportp(sb_port + DSP_WRITE_STATUS) & 0x80)) {
                        return 1;
                }
                delay(1);
        }
        return 0; // Timed out.
}


// Read data from Sound Blaster DSP.
int dsp_read(void)
{
        if (!wait_read()) {
                return -1;
        }
        return inportb(sb_port + DSP_READ);
}


// Write data byte or command to Sound Blaster DSP.
int dsp_write(int data)
{
        if (!wait_write()) {
                return 0;
        }
        outportb(sb_port + DSP_WRITE, data);
        return 1;
}


// Resets the DSP.
int dsp_reset(void)
{
        outportb(sb_port + DSP_RESET, 0x01);
        delay(1);
        outportb(sb_port + DSP_RESET, 0x00);
        if (dsp_read() == 0xAA) {
                return 1;
        }
        return 0;
}


// Commands the DSP to play 8-bit sound with the given number of samples.
int dsp_dma_dac(int length)
{
        if (!dsp_write(DSP_DMA_DAC)) {
                return 0;
        }
        if (!dsp_write(LOW(length - 1))) {
                return 0;
        }
        if (!dsp_write(HIGH(length - 1))) {
                return 0;
        }
        return 1;
}

// Commands the DSP to acquire a single 8-bit sample
int dsp_direct_adc()
{
        if (!dsp_write(DSP_DIRECT_ADC)) {
                return 0;
        }
        return dsp_read();
}


// Sets the DSP sampling rate, in hertz.
int dsp_set_time_constant(long sample_rate)
{
        if (!dsp_write(DSP_SET_TIME_CONSTANT)) {
                return 0;
        }
        if (!dsp_write(SAMPLE_RATE_TO_TC(sample_rate))) {
                return 0;
        }
        return 1;
}
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

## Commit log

2026-08-14 updated to kicad 9
    [SnarkBarker.csv, SnarkBarker.kicad_pcb, SnarkBarker.kicad_sch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]
2026-08-14 finalized the migration to kicad 9
    [SnarkBarker.kicad_pcb, SnarkBarker.kicad_sch]
2026-08-19 routing almost finished
    [SnarkBarker.kicad_pcb, SnarkBarker.kicad_sch]
2026-08-19 finalized routing
    [SnarkBarker.kicad_pcb, SnarkBarker.kicad_sch]
2026-08-19 finalized first revision
    [SnarkBarker.csv, SnarkBarker.kicad_pcb, SnarkBarker.kicad_sch]
2026-08-19 added bom readme

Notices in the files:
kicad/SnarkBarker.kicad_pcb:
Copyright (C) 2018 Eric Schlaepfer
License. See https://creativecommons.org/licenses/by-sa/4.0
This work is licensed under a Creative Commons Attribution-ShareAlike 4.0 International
